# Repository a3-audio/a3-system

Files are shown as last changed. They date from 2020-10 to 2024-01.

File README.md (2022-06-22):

# A³ Audio
Interact live with 3D Audio

## System
- A³ Motion: 4-Channel Motion Sampler
- A³ Mixer: 4-Channel DJ Mixer
- A³ Core: 3D Sound Server

## Homepage
- https://a3-audio.com

## Documentation
- https://doc.a3-audio.com

## Repository
- https://github.com/a3-audio/a3-system

## Contact
- Ticket [github-project](https://github.com/orgs/a3-audio/projects/1)
- Talk [mattermost](https://talk.a3-audio.com/ambisonics)
- E-Mail [contact@a3-audio.com](mailto:contact@a3-audio.com)

## Code of conduct
- Care the docs
- Keep the code clean
- We use [centralized workflow](https://www.git-scm.com/book/en/v2/Distributed-Git-Distributed-Workflows):
  - Don't edit the mainbranch. Use pull requests instead.
  - If you need an own different setup, fork this repo
  - Find us on stage
- Follow the <a href="https://contributor-covenant.org/">Contributor Covenant</a> Code of Conduct

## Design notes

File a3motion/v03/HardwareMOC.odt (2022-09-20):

# Power Supply

# Input

## Poti

### Notes

- The caps are a good idea. You might try putting a small one between the slider and ground.
- Setting REFS0 uses AVCC as the reference. I would set both REFS1 and REFS0 to zero and connect the top of the pot to AREF.
- Two fixed resistors is a good idea to rule out the pot's as the problem.
- Atmel recommends a max of 10K source impedance for 10 bit accuracy. A cap can help with this if the impedance is higher than 10K.10k impedance is what you would get when a 40k pot is in the middle position - 20k to VCC and 20k to GND makes 10k.
- So if you use pots lower than 40k in value, you might not need the caps.

## Encoder

### Schematic

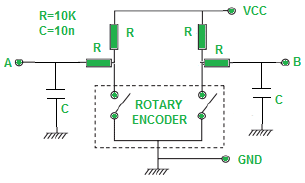
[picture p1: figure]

https://www.electroschematics.com/rotary-encoder-arduino/

with Hardware denoising.

But We will try without and go with software denoising

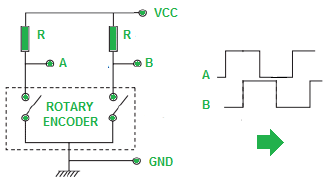
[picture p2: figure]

## Buttons

# LEDs

# TPIC6C595 (LED driver)

## Notes

- https://www.ti.com/lit/ds/symlink/tpic6c595.pdf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

## Overview

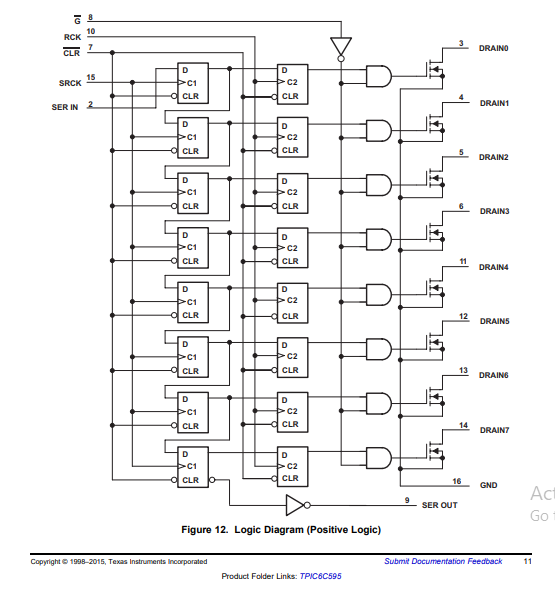
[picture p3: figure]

### Serial-In Interface

This device contains an 8-bit serial-in, parallel-out shift register that feeds an 8-bit D-type storage register. Data transfers through both the shift and storage registers on the rising edge of the shift register clock (SRCK) and the register clock (RCK), respectively. The storage register transfers data to the output buffer when shift register clear (CLR) is high.

### Clear Register

A logical low on (CLR) clears all registers in the device. TI suggests clearing the device during power up or initialization.

### Output Control

Holding the output enable (G) high holds all data in the output buffers low, and all drain outputs are off. Holding (G) low makes data from the storage register transparent to the output buffers. When data in the output buffers is low, the DMOS transistor outputs are off. When data is high, the DMOS transistor outputs have sink-current capability. This pin can also be used for global PWM dimming.

### Cascaded Application

The serial output (SER OUT) allows for cascading of the data from the shift register to additional devices. Connect the device (SEROUT) pin to the next device (SERIN) for daisy Chain.

### Daisy Chain

The typical application of TPIC6C595 is automotive cluster driver. In this example, two TPIC6C595 power shift registers are cascaded and used to turn on LEDs in the cluster panel. In this case, the LED must be updated after all 16 bits of data have been loaded into the serial shift registers. MCU outputs the data to the serial input (SER IN) while clocking the shift register clock (SRCK). After the 16th clock, a pulse to the register clock (RCK) transfers the data to the storage registers. If output enable (G) is low, then the LEDs are turned on corresponding to the status word with ones being on and zeros off. With this simple scheme, MCU can use the SPI interface to turn on 16 LEDs using only two ICs as illustrated in the image

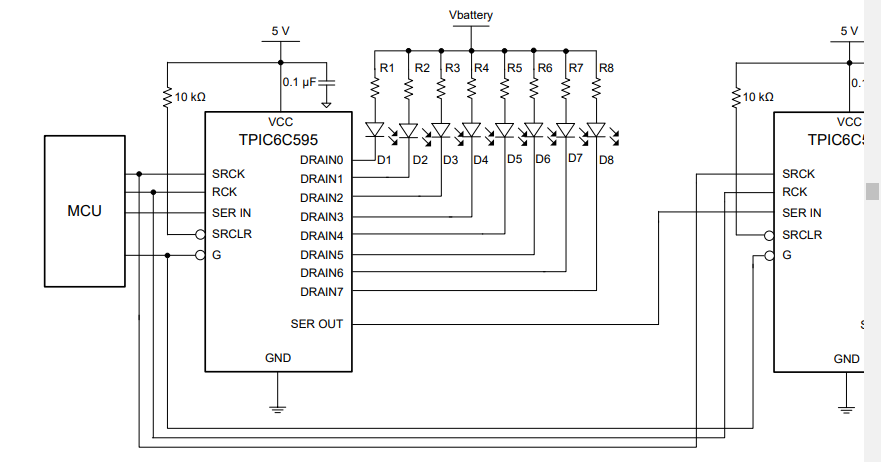
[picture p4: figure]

# Atmega

## ADC

### Notes

- The AVR has a neat feature... you use the internal 2.5V reference for the a/d, and hang a cap on the aref pin to suck up the ripple.
- The reference voltage is just the voltage at the top of the pot. It has a 100n cap to ground.
- I use the ADC Noise Reduction sleep during the conversion. or is this only available on the Atmega169?
- tried the ADC Noise Reduction on the 169, and found it didn't reduce the noise at all,
- siehe seite 196 für noise cancelation https://ww1.microchip.com/downloads/en/DeviceDoc/Atmel-2486-8-bit-AVR-microcontroller-ATmega8_L_datasheet.pdf

### design notes

Aref

- 100nF or 10nF on Aref. Other end on GND.
- Wenn man saubere Spannung hat kann man die auch da als Referenz anlegen

Vcc und Avcc (ADC supply) an 5V.

## I2C

## General IO

# Components

## TPIC6C595

- 1.3$ for DIP
- https://www.mouser.ph/ProductDetail/Texas-Instruments/TPIC6C595N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

## Socket

- 0.37$
- https://www.mouser.ph/ProductDetail/FCI-Amphenol/DILB16P-223TLF?qs=sGAEpiMZZMtneIuP4Zx3qQDrmajaGEu5

## Ceramic Capacitor 100nF

- 0.13$
- https://www.mouser.ph/ProductDetail/Vishay/K104M15X7RF53H5?qs=sGAEpiMZZMskC5GgilGuvlka1JhNGdVz

## Ceramic Capacitor 22pf

- 0.21$
- https://www.mouser.ph/ProductDetail/Vishay/K220J10C0GF5UH5?qs=sGAEpiMZZMvfWfew95%2FxXKwIr%252BteGxkk

## Electrolytic Capacitor 10uF

- 0.083$
- https://www.mouser.ph/ProductDetail/KEMET/ESC106M035AC3AA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

## Tactile Switches

- 2.79$
- https://www.mouser.ph/ProductDetail/CTS/228CMVARGBFR?qs=sGAEpiMZZMv0NwlthflBi6d2CTj%2FILa2s1KfV6ahLRE%3D

## Inductor

- 0.33$
- https://www.mouser.ph/ProductDetail/Bourns/78F100J-TR-RC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

## Header PIN Connector

- Don’t buy at distributor by pack somewhere else
- pitch 2.54mm x and y
- 1 2x2 male
- 1 1x6 female
- 1 1x5 female right angle
- 1 1x5 male right angle
- 2 1x2 female right angle
- 2 1x2 male right angle

## Poti Connector 1x5

# Mini-Lock Wire-to-Board

- Example: https://www.mouser.ph/ProductDetail/Molex/53426-0510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

## Crystal 16mhz

- https://www.mouser.ph/ProductDetail/IQD-Frequency-Products/LFXTAL036391Bulk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

## Encoder 24ppr

- 1.68$

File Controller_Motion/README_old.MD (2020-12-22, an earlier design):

# MOTION CONTROLLER

OSC TRANSMITTER AND PATTERNSAMPLER FOR 3-DIMENSIONAL AUDIO MOTION.

## OVERVIEW:

PLAYMODE
- PLAY
- RUNTIME-EDIT
    - Audio conversion mode (Mono, Stereo, VBAP, Ambisonic)
    - BPM
    - Width
    - Reverb
    - Beat: musical rhythm notation (1/4, 1/8, 3/4...)
    - Bars: length of patternloop
- STOP

SETUPMODE
- SPEAKERSETUP
    - Select Preset
    - Edit Preset
        - Number of loudspeakers
        - Select loudspeaker
        - Adjust position: azimuth, distance, elevation
    - Save and load, ask to enter new name or overwrite
- HEADPHONESETUP
    - Headphone sounds more realistic with fitting hrtf filtercurve
    - Select and load Preset
- PATTERNEDITOR
    - Select bank
    - Edit bank: touch a row or pattern to open "select -> Save -> bank/row/pattern dialog""
    - Save /bank/row/pattern
    - Load selection to buttonmatrix
- OPTIONS
    - Brightness
    - IP-Address, PORT this device
    - IP-Address, PORT to receiver
    - Export settings to usb

## HARDWARE LAYOUT
```
 CH1 CH2 CH3 CH4
  |   |   |   |
  v   v   v   v
|---------------|
| W | W | W | W | <- POTIS FOR WIDTH
|---------------|
| R | R | R | R | <- POTIS FOR REVERB
|---------------|
|               |
|               |
|               |
|               |
| TOUCHDISLPAY  | <- FANCY VISUALISATION OF CHANNELMOVEMENT
|               |
|               |
|               |
|               |
|---------------|
| E | E | E | E | <- ENCODER
|---------------|
| B | B | B | B | <- BUTTONS TO REC AND PLAY MOTION-PATTERNS
|---------------|    |
| B | B | B | B | <--|                        
|---------------|    |                 THE
| B | B | B | B | <--|            BUTTON-MATRIX 
|---------------|    |
| B | B | B | B | <--|
|---------------|
```

## DISPLAY LAYOUT
The touchscreen displays a lot of information but it makes sense in order 
to control and see all information on one fingertip.

```
       ch1            ch2           ch3            ch4        <- INFOFIELDS        
        |              |             |              |                 
        v              v             v              v                 
|-----------------------------------------------------------|         
| MODE:   MONO | MODE:   STER | MODE:   VBAP | MODE:   AMBI |         
| BEAT:   1/4  | BEAT:   1/4  | BEAT:   1/4  | BEAT:   1/4  |
| BARS:   4    | BARS:   4    | BARS:   4    | BARS:   4    |    
| WIDTH:  -    | WIDTH:  30°  | WIDTH:  20°  | WIDTH:  30°  |         
| REVERB: -    | REVERB: 30%  | REVERB: 30%  | REVERB: 30%  | 
| BPM:    128  | BPM:    128  | BPM:    128  | BPM:    128  |
|-----------------------------------------------------------|
|                            ch1                            |          
|                            sp2                            |
|                      __----ch2----__                      |
|                     L               R                     |
|                                                           |
|                                                           |
|                                                           |
|                                                           |
|  sp1                                                 sp3  |
|  ch1                                                 ch1  |
|                                                           |
|        R                                            L     |
|         |                                           |     | <- EAGLEVIEW: CURRENT SOUNDFIELD
|          |                                         |      |    
|         ch3                                       |       |    
|          |                                       ch4      |    
|           |                                       |       |
|            L                                     |        |
|                                                 |         |
|                                                 R         |
|                                                           |
|                                                           |
|                                                           |
|                                                           |
|             sp5                         sp4               |
|             ch1                         ch1               |
|                                                           |    
||1-------2-------3-------4-------5-------6-------7-------| | <- RUNTIME-EDIT: PATTERNLENGTH   
||->->->->->->->->->                                      | | <- RUNTIME-EDIT: PATTERNPROGRESS
|-----------------------------------------------------------|    
| RCV:192.168.178.125:1234|SND:192.168.178.126:1232|BPM:128 | <- SYSTEMVIEW
|-----------------------------------------------------------|

TOUCHDISPLAY LEGEND:
- INFOFIELD: COLORS - 4 channels, 4 infofield areas, 4 different colors
- INFOFIELD: MODE - The Stereosource will be converted to Mono, Stereo, VBAP or Ambisonic
- INFOFIELD: WIDTH - How wide your sources spread in the sphere (exept monomode)
- INFOFIELD: REVERB - An Ambisonic Reverb reflects from all directions (except monomode)
- INFOFIELD: BPM - Calculated BPM for each Track, cool to run musicious motionpatterns
- INFOFIELD: BEAT - Map motionpatterns on estimated BPM
- INFOFIELD: BARS - Lenght of motionsequenz

- EAGLEVIEW: SP - The speakerposition
- EAGLEVIEW: CH - The channelposition (channels are colorcoded)
- EAGLEVIEW: LR - The width of a stereosource
- EAGLEVIEW: .. - These thin colored lines connecting straight to corresponding infofield

- SYSTEMVIEW: RCV - This device OSC input
- SYSTEMVIEW: SND - This device OSC output
- SYSTEMVIEW: BPM - Master BPM
```
## PLAYMODE
- Encoder 1-4: Push

### PLAYMODE: PLAY
- Encoder 1-4 Push: Toggle RUNTIME-EDIT Mode for this channel
- Encoder 1-4 Double Push: Enter Setup Page 1-4
- Buttonmatrix Push: play pattern
- Buttonmatrix Double Push: toggle repeat 

### PLAYMODE: RUNTIME-EDIT
- Encoder - Push: Toggle through INFOFIELD-options
- Encoder - Turn: Adjust option
    - MODE: mono, stereo, vbap, ambisonic
    - BEAT: 1/4, 1/8, 1/16, 2/3, ... 
    - BARS: length of patternloop
    - WIDTH: Spread stereo
    - REVERB: Adjust reverblevel
- Touchdisplay onTouch: Records Motion to cachefile
- Touchdisplay onRelease: Plays Motion from cachefile
- Buttonmatrix long press: Stores cachefile to BUTTON
- Encorder Double Push: Exit to PLAYMODE

### PLAYMODE: STOP
- Somewhere should be a resetbutton, or steady scenes in patterns?

## SETUPMODE
Encoder 1-4: Double-Push. 

### SPEAKERSETUP: SELECT PRESET
Encoder 1: Double-Push
- Encoder 1 Turn: Select Preset - SELECT overlay
- Encoder 1 Push: Load Preset 

### SPEAKERSETUP: EDIT PRESET
Encoder 2: Double-Push
- Encoder 1 Turn: Set Number of outputs
- Encoder 2 Turn: Select output
- Encoder 3 Turn: Set Azimuth for selected output
- Encoder 4 Turn: Set Distance for selected output

### SPEAKERSETUP: SAVE AND LOAD
- Display Button SAVE: SAVE TO .. overlay
- Display Button DISCARD: Discard changes
- Display Button ENABLE: Upload Speakerlayout to Audioengine
- Display Button EXIT: Return to PLAYMODE and open dialog "save changes?" [yes, dismiss]
```
|-----------------------------------------------|
| SPEAKERSETUP                                  | <- SPEAKERSETUP: SELECT PRESET
| 5 CHANNEL CIRCLE WITH DISTANCE 4.5m           |
|-----------------------------------------------|
| OUTPUTS  |  SELECT   |  AZIMUTH  |  DISTANCE  | <- SPEAKERSETUP: EDIT PRESET
| 5        |  sp1      |  -80°     |  4.5m      |
|-----------------------------------------------|
|                                               |
|                     sp2                       |
|        |sp1|                    sp3           |
|                                               |
|                                               | <- VISUALISATION OF SPEAKERSETUP
|                                               |
|                                               |  
|               sp5        sp4                  |
|                                               |
|                                               |
|-----------------------------------------------|
|-----------------------------------------------|
|          |           |            |           |
|   SAVE   |  DISCARD  |   ENABLE   |   EXIT    | <- SPEAKERSETUP: SAVE AND LOAD                   
|          |           |            |           |
------------------------------------------------|

SELECT and SAVE TO.. - OVERLAY
- Encoder 1 Turn: select
- Encoder 1 push: enter selection

|-----------------------------------------------|
| SPEAKERSETUP                                  |
| 5 CHANNEL CIRCLE WITH DISTANCE 4.5m           |
|-----------------------------------------------|
| OUTPUTS  |  SELECT   |  AZIMUTH  |  DISTANCE  |             
| 5        |  sp1      |  -80°     |  4.5m      |
|-----------------------------------------------|
|                                               |
|                     sp2                       |
|    |-------------------------------------|    |
|    |             Burning Man 2021        |    |
|    | selected -> GARBICZ 2019            |    |                        
|    |             Gardelegen 2018         |    |
|    |--------------------------------------    |  
|               sp5        sp4                  |
|                                               |
|                                               |
|-----------------------------------------------|
|-----------------------------------------------|
|          |           |            |           |
|   SAVE   |  DISCARD  |   ENABLE   |   EXIT    |                                                 
|          |           |            |           |
|-----------------------------------------------|

A common workflow, starting from PLAYMODE:
- Encoder 1: Double Push - enter SPEAKERSETUP
- Encoder 1: Turn - Select speakerlayout
- Encoder 1: Push - Edit speakerlayout
- Encoder 2: Double Push - enter SETUPMODE LEVEL 2
- Encoder 1: Turn - Adjust number of speaker outputs
- Encoder 2: Turn - Select speaker 1
- Encoder 3: Turn - Adjust Azimuth of speaker 1(-180°, 180°)
- Encoder 4: Turn - Adjust Distanz of speaker 2
- Repeat the last 3 steps for all your speaker
- Display Button SAVE: Save your speakerlayout
- Display Button ENABLE: Upload your setup to audioengine
- Display Button EXIT: Exit to PLAYMODE
```

### HEADPHONESETUP
Encoder 3: Double-Push
- Encoder 1 Turn: Select preset - SELECT overlay
- Encoder 1 Push: Enable preset

### PATTERNEDITOR: LAYOUT SELECT / EDIT
Encoder 4: Double-Push
- Encoder 1 Turn: Select BANK preset - SELECT overlay
- Encoder 1 Push: Load BANK preset to editor
- Encoder 2 Turn: Select ROW preset - SELECT Overlay
    - Encoder 1-4 Push: Load ROW to BANK
    - Encoder 1-4 Hold: Load ROW on BUTTONMATRIX
- Display Button PATTERN: Select PATTERN preset - SELECT overlay
    - Encoder 1 Turn: Select PATTERN preset
    - Encoder 1 Push: Load PATTERN preset to PATTERN

### PATTERNEDITOR: SAVE AND LOAD
- Display Button SAVE: SAVE TO .. overlay
- Display Button DISCARD: Discard changes
- Display Button ENABLE: Upload patternlayout to audioengine
- Display Button EXIT: Return to PLAYMODE and open dialog "save changes?" [yes, dismiss]

```
|-----------------------------------------------|
| PRESET BANK/ROW/PATTERN                       | <- LEVEL 3
| Presetbank: user                              |
|-----------------------------------------------|
|   ROW 1   |   ROW 2   |   ROW 3   |   ROW 4   | <- 
|-----------------------------------------------|
|           |           |           |           |
|  PATTERN  |  PATTERN  |  PATTERN  |  PATTERN  |
|           |           |           |           |
|-----------------------------------------------|
|           |           |           |           |
| 1/4 right |  PATTERN  |  PATTERN  |  PATTERN  |
|           |           |           |           |
|-----------------------------------------------| <- PREVIEW BUTTONMATRIXLAYOUT
|           |           |           |           | 
| 1/8 rand  |  PATTERN  |  PATTERN  |  PATTERN  |
|           |           |           |           |
|-----------------------------------------------|
|           |           |           |           |
| 1/16 diag |  PATTERN  |  PATTERN  |  PATTERN  |
|           |           |           |           |
|-----------------------------------------------|
|-----------------------------------------------|
|           |           |           |           |
|   SAVE    |  DISCARD  |  ENABLE   |   EXIT    |                                  
|           |           |           |           |
------------------------------------------------|

SELECT and SAVE TO.. - OVERLAY
- Encoder 1 Turn: Select Buttonpattern
- Encoder 1 Push: Load Buttonpattern

|-------------------------------------------------|
| BUTTONMATRIX LAYOUT                             |  <- LEVEL 3
| USERSPACE 1                                     |
|-------------------------------------------------|
|   ROW 1   |   ROW 2    |   ROW 3    |   ROW 4   |
|-------------------------------------------------|
|           |            |            |           |
| 1/4 left  |    ...     |    ...     |    ...    |
|           |            |            |           |
|-------------------------------------------------|
|           |            |            |           |
| 1/4 |-------------------------------------|.    |
|     |             1/4 left                |     |
|-----| selected -> 1/4 RIGHT               |-----| <- PAD-SELECTION OVERLAY
|     |             1/8 random              |     |                           
| 1/8 |--------------------------------------.    |
|           |            |            |           |
|-------------------------------------------------|
|           |            |            |           |
| 1/16 left |    ...     |    ...     |    ...    |
|           |            |            |           |
|-------------------------------------------------|
|-------------------------------------------------|
|                        |                        |
|      SAVE & EXIT       |     DISCARD & EXIT     |                                  
|                        |                        |
--------------------------------------------------|

PATTERNEDITOR BACKEND:
Example - Presetbank "smooth" 

Stored informations:
- Bankname
- Banklayout
- Rownames
- Rowlayouts
- Patternnames
- Patternconfig

If folder smooth contains a .ini file and subfolders, its a bank.
If it contains .ini file and .ptn files, its a row.

└── glitter
└── smooth
    ├── smooth.ini
    ├── Antropofagia
    │   ├── layout.ini
    │   ├── drop.ptn
    │   ├── intro.ptn
    │   ├── steady.ptn
    │   └── woof.ptn
    ├── Kaluma
    │   ├── layout.ini
    │   ├── drop.ptn
    │   ├── intro.ptn
    │   ├── steady.ptn
    │   └── woof.ptn
    ├── LostMemory
    │   ├── layout.ini
    │   ├── drop.ptn
    │   ├── intro.ptn
    │   ├── steady.ptn
    │   └── woof.ptn
    └── SixthSense
        ├── layout.ini
        ├── drop.ptn
        ├── intro.ptn
        ├── steady.ptn
        └── woof.ptn

A common Workflow starting from PLAYMODE:
- Encoder 3 Double push: Enter PATTERNEDITOR
- Encoder 1 Turn: Select presetbank
- Encoder 1 Push: Edit selected presetbank 
- Encoder 2 Turn: Select strip
- Display Button ROW 1-4: Load selected strip
- Encoder 3 Turn: Select pattern
- Display Button PATTERN: Load selected PATTERN
- Display Button SAVE: SAVE TO .. popup
- Display Button DISCARD: Discard changes
- Display Button ENABLE: Load current Layout to Buttonmatrix
- Display Button EXIT: Return to PLAYMODE and open dialog "save changes?" [yes, dismiss]

Note: Factorypresets are writeprotected but you can edit and store them as userpreset.
You can store motions in pattern, pattern in rows and rows in banks banks.
```

### OPTIONS
- Brightness
- IP-Address and Port Motioncontroller
- IP-Address and Port audioengine
- Export settings to usb

## OSC
``` 
# TRANSMIT
/ambijockey/moc/ch/1-4/mode/ [0-3] (Mono, Stereo, VBAP, Ambisonic)
/ambijockey/moc/ch/1-4/motion/ xy [0-1]
/ambijockey/moc/ch/1-4/width/ [0-1]
/ambijockey/moc/ch/1-4/reverb/ [0-1]

/ambijockey/moc/speakersetup/n [1-24]
/ambijockey/moc/speakersetup/n/azimuth [-180-180]
/ambijockey/moc/speakersetup/n/Distance [m]

# RECEIVE
/ambijockey/moc/ch/1-4/motion/ xy [0-1]
/ambijockey/moc/ch/1-4/vu/ [0-1]
/ambijockey/moc/ch/1-4/bpm/ [80-180]
/ambijockey/moc/master/bpm/ [80-180]
```

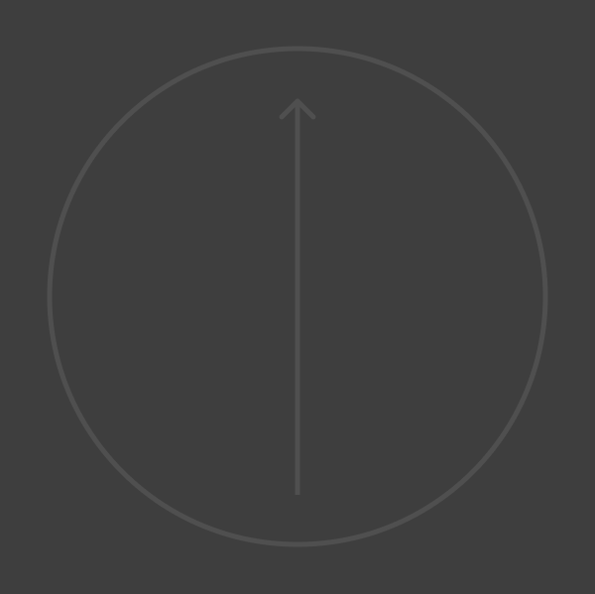
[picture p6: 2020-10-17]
Controller_Motion/software/python/GUI/Pix/MoverMeterBG.png

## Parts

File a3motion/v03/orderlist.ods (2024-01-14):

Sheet: Sheet1
Wie viele tatsächlich benätigt werden |  |  | Bauteil Beschreibung
rpi connect | poti | main | name | bauform | suchbegriff | wie viel ordern | Variation | link für order
 |  | 5 | 100nF | 1206 | Cap | 1 | 100nF | AE:32966490820
 |  | 1 | 10uF | D 4.0mm P1.5 | Elko | 1 | 25V10uF 5x11mm 50p | AE: 1005001429282858
 |  | 1 | 1x5 | P2.54 | Horiz Pinconnector male | 2 | 1row curved male | https://www.aliexpress.com/item/4001112688385.html?spm=a2g0o.cart.0.0.6f5f38dak9MJmX&mp=1
 |  | 1 | 1x5 | P2.54 | Horiz Pinconnector female | 2 | 1row curved female | https://www.aliexpress.com/item/4001112688385.html?spm=a2g0o.cart.0.0.6f5f38dak9MJmX&mp=1
 | 1 | 1 | 1x5 | P2.50 | JST_XH_B5B-XH-A P2.50mm | 2 |  | https://www.digikey.de/de/products/detail/jst-sales-america-inc/B5B-XH-A-LF-SN/1530483
 |  | 1 | 1x3 | P2.54 | Vert Pinconnector male | 0 |  | ok Empty
 |  | 1 | 2x2 | P2.54 | Vert Pinconnector male | 1 | 2row male | https://www.aliexpress.com/item/4001112688385.html?spm=a2g0o.cart.0.0.6f5f38dak9MJmX&mp=1
 |  | 3 | 0R | 1206 | Resistor | 1 | 0R | https://www.aliexpress.com/item/1005001794416354.html?spm=a2g0o.cart.0.0.6f5f38dak9MJmX&mp=1
 | 2 | 6 | 4k7 | 1206 | Resistor | 1 | 4.7k | https://www.aliexpress.com/item/1005001794416354.html?spm=a2g0o.cart.0.0.6f5f38dak9MJmX&mp=1
 |  | 8 | 155R | 1206 | Resistor | 1 | 155R | https://www.aliexpress.com/item/1005001794416354.html?spm=a2g0o.cart.0.0.6f5f38dak9MJmX&mp=1
 |  | 4 | 100R | 1206 | Resistor | 1 | 100R | https://www.aliexpress.com/item/1005001794416354.html?spm=a2g0o.cart.0.0.6f5f38dak9MJmX&mp=1
 |  | 2 | 27k | 1206 | Resistor | 1 | 27k | https://www.aliexpress.com/item/1005001794416354.html?spm=a2g0o.cart.0.0.6f5f38dak9MJmX&mp=1
 |  | 4 | Buttons |  | MO:228CMVARGBFR | 4 |  | https://www.mouser.de/ProductDetail/CTS-Electronic-Components/228CMVARGBFR?qs=gTYE2QTfZfSFpUQ%252Bb6QA4w%3D%3D
 |  | 1 | Rotary_Encoder_Switch |  | PEC11R-4230K-S0024 | 1 |  | https://www.digikey.de/de/products/detail/bourns-inc/PEC11R-4230K-S0024/7314923
 |  | 2 | SOIC-16_3.9x9.9mm | P1.27mm | TPIC6C595 | 2 |  | https://www.mouser.de/ProductDetail/STMicroelectronics/STPIC6C595MTR?qs=w3gjcs3NwcgP4BoIb%252B0GuQ%3D%3D
 |  | 1 | ATtiny1626 |  | MO:556-ATTINY1626-SF | 1 |  | https://www.mouser.de/ProductDetail/Microchip-Technology-Atmel/ATTINY1626-SF?qs=vmHwEFxEFR87MXV%2FJYMLYg%3D%3D
 | 2 |  | 50k Poti |  | DK:PT01-D130D-B503 | 1 | 50K | https://www.aliexpress.com/item/4001230670074.html?spm=a2g0o.cart.0.0.6f5f38dak9MJmX&mp=1
1 |  |  | 1x5 | P2.54 | Vert Pinconnector male | 4 |  | https://www.aliexpress.com/item/4001112688385.html?spm=a2g0o.cart.0.0.6f5f38dak9MJmX&mp=1
1 |  |  | 2x5 | P2.54 | Vert Pinconnector female | 2 | 2row female | https://www.aliexpress.com/item/4001112688385.html?spm=a2g0o.cart.0.0.6f5f38dak9MJmX&mp=1
2 |  |  | BSS138 | SOT-23 | DK:BSS138LT1G | 2 |  | https://www.aliexpress.com/item/1948601004.html?spm=a2g0o.cart.0.0.6f5f38dak9MJmX&mp=1
4 |  |  | 10k | 1206 | Resistor | 1 | 10k | https://www.aliexpress.com/item/1005001794416354.html?spm=a2g0o.cart.0.0.6f5f38dak9MJmX&mp=1
1 |  |  | USB-C |  | MO:640-USB4125-GF-A-190 | 1 |  | https://www.mouser.de/ProductDetail/GCT/USB4125-GF-A-0190?qs=QNEnbhJQKvbCz4hEJBS24w%3D%3D
 |  |  |  |  |  |  |  | https://www.aliexpress.com/item/1005001429282858.html?spm=a2g0o.cart.0.0.76f038dagCkkKq&mp=1

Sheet: order
Wie viele tatsächlich benätigt werden |  |  | Bauteil Beschreibung
rpi connect | poti | main | name | bauform | suchbegriff | wie viel ordern | Variation | link für order
 | 1 | 1 | 1x5 | P2.50 | JST_XH_B5B-XH-A P2.50mm | 2 |  | https://www.digikey.de/de/products/detail/jst-sales-america-inc/B5B-XH-A-LF-SN/1530483
 |  | 1 | Rotary_Encoder_Switch |  | PEC11R-4230K-S0024 | 1 |  | https://www.digikey.de/de/products/detail/bourns-inc/PEC11R-4230K-S0024/7314923
 |  | 2 | SOIC-16_3.9x9.9mm | P1.27mm | TPIC6C595 | 2 |  | https://www.digikey.de/de/products/detail/stmicroelectronics/STPIC6C595MTR/634787
 |  | 3 | 0R | 1206 | Resistor | 1 | 0R | https://www.aliexpress.com/item/1005001794416354.html?spm=a2g0o.cart.0.0.6f5f38dak9MJmX&mp=1
 | 2 | 6 | 4k7 | 1206 | Resistor | 1 | 4.7k | https://www.aliexpress.com/item/1005001794416354.html?spm=a2g0o.cart.0.0.6f5f38dak9MJmX&mp=1
 |  | 8 | 155R | 1206 | Resistor | 1 | 155R | https://www.aliexpress.com/item/1005001794416354.html?spm=a2g0o.cart.0.0.6f5f38dak9MJmX&mp=1
 |  | 4 | 100R | 1206 | Resistor | 1 | 100R | https://www.aliexpress.com/item/1005001794416354.html?spm=a2g0o.cart.0.0.6f5f38dak9MJmX&mp=1
 |  | 2 | 27k | 1206 | Resistor | 1 | 27k | https://www.aliexpress.com/item/1005001794416354.html?spm=a2g0o.cart.0.0.6f5f38dak9MJmX&mp=1
4 |  |  | 10k | 1206 | Resistor | 1 | 10k | https://www.aliexpress.com/item/1005001794416354.html?spm=a2g0o.cart.0.0.6f5f38dak9MJmX&mp=1
 | 2 |  | 50k Poti |  | DK:PT01-D130D-B503 | 1 | 50K | https://www.aliexpress.com/item/4001230670074.html?spm=a2g0o.cart.0.0.6f5f38dak9MJmX&mp=1
2 |  |  | BSS138 | SOT-23 | DK:BSS138LT1G | 2 |  | https://www.aliexpress.com/item/1948601004.html?spm=a2g0o.cart.0.0.6f5f38dak9MJmX&mp=1
 |  | 1 | 10uF | D 4.0mm P1.5 | Elko | 1 | 25V10uF 5x11mm 50p | https://www.aliexpress.com/item/1005001429282858.html?spm=a2g0o.cart.0.0.76f038dagCkkKq&mp=1
 |  | 5 | 100nF | 1206 | Cap | 1 | 100nF | https://www.aliexpress.com/item/32966490820.html?spm=a2g0o.cart.0.0.693a38da32krFN&mp=1
 |  | 1 | 1x5 | P2.54 | Horiz Pinconnector male | 2 | 1row curved male | https://www.aliexpress.com/item/4001112688385.html?spm=a2g0o.cart.0.0.6f5f38dak9MJmX&mp=1
 |  | 1 | 1x5 | P2.54 | Horiz Pinconnector female | 2 | 1row curved female | https://www.aliexpress.com/item/4001112688385.html?spm=a2g0o.cart.0.0.6f5f38dak9MJmX&mp=1
 |  | 1 | 2x2 | P2.54 | Vert Pinconnector male | 1 | 2row male | https://www.aliexpress.com/item/4001112688385.html?spm=a2g0o.cart.0.0.6f5f38dak9MJmX&mp=1
1 |  |  | 1x5 | P2.54 | Vert Pinconnector male | 4 |  | https://www.aliexpress.com/item/4001112688385.html?spm=a2g0o.cart.0.0.6f5f38dak9MJmX&mp=1
1 |  |  | 2x5 | P2.54 | Vert Pinconnector female | 2 | 2row female | https://www.aliexpress.com/item/4001112688385.html?spm=a2g0o.cart.0.0.6f5f38dak9MJmX&mp=1
1 |  |  | USB-C |  | MO:640-USB4125-GF-A-190 | 1 |  | https://www.mouser.de/ProductDetail/GCT/USB4125-GF-A-0190?qs=QNEnbhJQKvbCz4hEJBS24w%3D%3D
 |  | 1 | ATtiny1626 |  | MO:556-ATTINY1626-SF | 1 |  | https://www.mouser.de/ProductDetail/Microchip-Technology-Atmel/ATTINY1626-SF?qs=vmHwEFxEFR87MXV%2FJYMLYg%3D%3D
 |  | 4 | Buttons |  | MO:228CMVARGBFR | 4 |  | https://www.mouser.de/ProductDetail/CTS-Electronic-Components/228CMVARGBFR?qs=gTYE2QTfZfSFpUQ%252Bb6QA4w%3D%3D
 |  | 1 | 1x3 | P2.54 | Vert Pinconnector male | 0 |  | ok Empty

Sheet: calc
poti pcb (6x) | 21.06
Button pcb (6x) | 61.62
rpi connector (3x) | 10.98
AliExpress | 71.27
DigiKey | 39.16
mouser | 95.22
 | 299.31

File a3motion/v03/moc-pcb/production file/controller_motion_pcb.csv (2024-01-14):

Source: | C:\Users\tirii\Documents\Ambisonic\a3-hardware\a3motion\v03\Mainboard-pcb\controller_motion_pcb.kicad_sch
Date: | 27/09/2022 13:00:52
Tool: | Eeschema (6.0.0)
Generator: | C:\Program Files\KiCad\6.0\bin\scripting\plugins/bom_csv_grouped_by_value.py
Component Count: | 42
Individual Components:
Item | Qty | Reference(s) | Value | LibPart | Footprint | Datasheet | Description | Height | Manufacturer_Name | Manufacturer_Part_Number | Mouser Part Number | Mouser Price/Stock
 |  | C1 | 100nF | Device:C | Capacitor_SMD:C_1206_3216Metric_Pad1.33x1.80mm_HandSolder | DK:1206B104K500BD
 |  | C2 | 100nF | Device:C | Capacitor_SMD:C_1206_3216Metric_Pad1.33x1.80mm_HandSolder | DK:1206B104K500BD
 |  | C3 | 100nF | Device:C | Capacitor_SMD:C_1206_3216Metric_Pad1.33x1.80mm_HandSolder | DK:1206B104K500BD
 |  | C4 | 100nF | Device:C | Capacitor_SMD:C_1206_3216Metric_Pad1.33x1.80mm_HandSolder | DK:1206B104K500BD
 |  | C5 | 10uF | Device:CP | Capacitor_THT:CP_Radial_D4.0mm_P1.50mm | DK:35ML10MEFCT54X7
 |  | C6 | 100nF | Device:C | Capacitor_SMD:C_1206_3216Metric_Pad1.33x1.80mm_HandSolder | DK:1206B104K500BD
 |  | J1 | SPI_Female | Connector:Conn_01x05_Female | Connector_PinSocket_2.54mm:PinSocket_1x05_P2.54mm_Horizontal | DK:PPTC051LGBN-RC
 |  | J2 | SPI_Male | Connector:Conn_01x05_Male | Connector_PinHeader_2.54mm:PinHeader_1x05_P2.54mm_Horizontal | DK:61300511021
 |  | J3 | Conn_01x05 | Connector:Conn_01x05_Female | 3dAudioFoot:JST_XH_B5B-XH-A_1x05_P2.50mm_Vertical | DK:B5B-XH-A
 |  | J4 | UPDI_Interface | Connector:Conn_01x03_Male | Connector_PinHeader_2.54mm:PinHeader_1x03_P2.54mm_Vertical | DK:61300311121
 |  | J5 | Programm_Jumper | Connector:Conn_02x02_Male | Connector_PinHeader_2.54mm:PinHeader_2x02_P2.54mm_Vertical | DK:61300421121
 |  | R1 | 0R | Device:R | Resistor_SMD:R_1206_3216Metric_Pad1.30x1.75mm_HandSolder | 1206 Resistor 5%
 |  | R2 | 0R | Device:R | Resistor_SMD:R_1206_3216Metric_Pad1.30x1.75mm_HandSolder | 1206 Resistor 5%
 |  | R3 | 4k7 | Device:R | Resistor_SMD:R_1206_3216Metric_Pad1.30x1.75mm_HandSolder | 1206 Resistor 5%
 |  | R4 | 4k7 | Device:R | Resistor_SMD:R_1206_3216Metric_Pad1.30x1.75mm_HandSolder | 1206 Resistor 5%
 |  | R5 | 165 | Device:R | Resistor_SMD:R_1206_3216Metric_Pad1.30x1.75mm_HandSolder | 1206 Resistor 5%
 |  | R6 | 155 | Device:R | Resistor_SMD:R_1206_3216Metric_Pad1.30x1.75mm_HandSolder | 1206 Resistor 5%
 |  | R7 | 100 | Device:R | Resistor_SMD:R_1206_3216Metric_Pad1.30x1.75mm_HandSolder | 1206 Resistor 5%
 |  | R8 | 165 | Device:R | Resistor_SMD:R_1206_3216Metric_Pad1.30x1.75mm_HandSolder | 1206 Resistor 5%
 |  | R9 | 155 | Device:R | Resistor_SMD:R_1206_3216Metric_Pad1.30x1.75mm_HandSolder | 1206 Resistor 5%
 |  | R10 | 100 | Device:R | Resistor_SMD:R_1206_3216Metric_Pad1.30x1.75mm_HandSolder | 1206 Resistor 5%
 |  | R11 | 165 | Device:R | Resistor_SMD:R_1206_3216Metric_Pad1.30x1.75mm_HandSolder | 1206 Resistor 5%
 |  | R12 | 155 | Device:R | Resistor_SMD:R_1206_3216Metric_Pad1.30x1.75mm_HandSolder | 1206 Resistor 5%
 |  | R13 | 100 | Device:R | Resistor_SMD:R_1206_3216Metric_Pad1.30x1.75mm_HandSolder | 1206 Resistor 5%
 |  | R14 | 165 | Device:R | Resistor_SMD:R_1206_3216Metric_Pad1.30x1.75mm_HandSolder | 1206 Resistor 5%
 |  | R15 | 155 | Device:R | Resistor_SMD:R_1206_3216Metric_Pad1.30x1.75mm_HandSolder | 1206 Resistor 5%
 |  | R16 | 100 | Device:R | Resistor_SMD:R_1206_3216Metric_Pad1.30x1.75mm_HandSolder | 1206 Resistor 5%
 |  | R17 | 27k | Device:R | Resistor_SMD:R_1206_3216Metric_Pad1.30x1.75mm_HandSolder | 1206 Resistor 5%
 |  | R18 | 27k | Device:R | Resistor_SMD:R_1206_3216Metric_Pad1.30x1.75mm_HandSolder | 1206 Resistor 5%
 |  | R19 | 4k7 | Device:R | Resistor_SMD:R_1206_3216Metric_Pad1.30x1.75mm_HandSolder | 1206 Resistor 5%
 |  | R20 | 4K7 | Device:R | Resistor_SMD:R_1206_3216Metric_Pad1.30x1.75mm_HandSolder | 1206 Resistor 5%
 |  | R21 | 4K7 | Device:R | Resistor_SMD:R_1206_3216Metric_Pad1.30x1.75mm_HandSolder | 1206 Resistor 5%
 |  | R22 | 4k7 | Device:R | Resistor_SMD:R_1206_3216Metric_Pad1.30x1.75mm_HandSolder | 1206 Resistor 5%
 |  | R23 | 0R | Device:R | Resistor_SMD:R_1206_3216Metric_Pad1.30x1.75mm_HandSolder | 1206 Resistor 5%
 |  | S1 | 228CMVARGBFR | 3dAudioSym:228CMVARGBFR | 3dAudioFoot:228CMVARGBFR_SMD | MO:228CMVARGBFR | Tactile Switches Color Red,Green,Blue SMD Gullwing | 7.3 | CTS | 228CMVARGBFR | 774-228CMVARGBFR | https://www.mouser.co.uk/ProductDetail/CTS-Electronic-Components/228CMVARGBFR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
 |  | S2 | 228CMVARGBFR | 3dAudioSym:228CMVARGBFR | 3dAudioFoot:228CMVARGBFR_SMD | MO:228CMVARGBFR | Tactile Switches Color Red,Green,Blue SMD Gullwing | 7.3 | CTS | 228CMVARGBFR | 774-228CMVARGBFR | https://www.mouser.co.uk/ProductDetail/CTS-Electronic-Components/228CMVARGBFR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
 |  | S3 | 228CMVARGBFR | 3dAudioSym:228CMVARGBFR | 3dAudioFoot:228CMVARGBFR_SMD | MO:228CMVARGBFR | Tactile Switches Color Red,Green,Blue SMD Gullwing | 7.3 | CTS | 228CMVARGBFR | 774-228CMVARGBFR | https://www.mouser.co.uk/ProductDetail/CTS-Electronic-Components/228CMVARGBFR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
 |  | S4 | 228CMVARGBFR | 3dAudioSym:228CMVARGBFR | 3dAudioFoot:228CMVARGBFR_SMD | MO:228CMVARGBFR | Tactile Switches Color Red,Green,Blue SMD Gullwing | 7.3 | CTS | 228CMVARGBFR | 774-228CMVARGBFR | https://www.mouser.co.uk/ProductDetail/CTS-Electronic-Components/228CMVARGBFR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
 |  | SW1 | Rotary_Encoder_Switch | Device:Rotary_Encoder_Switch | 3dAudioFoot:PEC11R4230KS0024 | DK:PEC11R-4230K-S0024
 |  | U1 | TPIC6C595 | 3dAudioSym:TPIC6C595 | Package_SO:SOIC-16_3.9x9.9mm_P1.27mm | MO:511-STPIC6C595MTR
 |  | U2 | TPIC6C595 | 3dAudioSym:TPIC6C595 | Package_SO:SOIC-16_3.9x9.9mm_P1.27mm | MO:511-STPIC6C595MTR
 |  | U3 | ATtiny1626 | 3dAudioSym:ATtiny1626 | 3dAudioFoot:attiny1626 | MO:556-ATTINY1626-SF
 | DK ? digikey MO ? Mouser

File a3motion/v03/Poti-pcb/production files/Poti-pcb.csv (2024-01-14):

Source: | C:\Users\tirii\Documents\Ambisonic\a3-hardware\a3motion\v03\Poti-pcb\Poti-pcb.kicad_sch
Date: | 27/09/2022 13:05:09
Tool: | Eeschema (6.0.0)
Generator: | C:\Program Files\KiCad\6.0\bin\scripting\plugins/bom_csv_grouped_by_value.py
Component Count: | 5
Individual Components:
Item | Qty | Reference(s) | Value | LibPart | Footprint | Datasheet
 |  | J1 | Conn_01x05_Male | Connector:Conn_01x05_Male | 3dAudioFoot:JST_XH_B5B-XH-A_1x05_P2.50mm_Vertical | DK:B5B-XH-A
 |  | R1 | 4k7 | Device:R | Resistor_SMD:R_1206_3216Metric_Pad1.30x1.75mm_HandSolder | 1206 5%
 |  | R2 | 4k7 | Device:R | Resistor_SMD:R_1206_3216Metric_Pad1.30x1.75mm_HandSolder | 1206 5%
 |  | RV1 | 10k Poti | Device:R_Potentiometer | Potentiometer_THT:Potentiometer_Alpha_RD901F-40-00D_Single_Vertical_CircularHoles | DK:PT01-D130D-B503
 |  | RV2 | 10k Poti | Device:R_Potentiometer | Potentiometer_THT:Potentiometer_Alpha_RD901F-40-00D_Single_Vertical_CircularHoles | DK:PT01-D130D-B503
 | DK ? Digikey MO ? Mouser

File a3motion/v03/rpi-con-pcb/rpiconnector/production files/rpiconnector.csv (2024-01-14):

Source: | C:\Users\tirii\Documents\Ambisonic\a3-hardware\a3motion\v03\RPIconnector\rpiconnector\rpiconnector.kicad_sch
Date: | 27/09/2022 12:04:25
Tool: | Eeschema (6.0.0)
Generator: | C:\Program Files\KiCad\6.0\bin\scripting\plugins/bom_csv_grouped_by_value.py
Component Count: | 9
Individual Components:
Item | Qty | Reference(s) | Value | LibPart | Footprint | Datasheet
 |  | J1 | Conn_01x05_Male | Connector:Conn_01x05_Male | Connector_PinHeader_2.54mm:PinHeader_1x05_P2.54mm_Vertical | DK:61300511121
 |  | J2 | Conn_02x05_Odd_Even | Connector_Generic:Conn_02x05_Odd_Even | Connector_PinHeader_2.54mm:PinHeader_2x05_P2.54mm_Vertical | MO:649-68046-605PLF
 |  | Q1 | BSS138 | Transistor_FET:BSS138 | Package_TO_SOT_SMD:SOT-23 | DK:BSS138LT1G
 |  | Q2 | BSS138 | Transistor_FET:BSS138 | Package_TO_SOT_SMD:SOT-23 | DK:BSS138LT1G
 |  | R1 | 10k | Device:R | Resistor_SMD:R_1206_3216Metric_Pad1.30x1.75mm_HandSolder | 1206 5%
 |  | R2 | 10k | Device:R | Resistor_SMD:R_1206_3216Metric_Pad1.30x1.75mm_HandSolder | 1206 5%
 |  | R3 | 10k | Device:R | Resistor_SMD:R_1206_3216Metric_Pad1.30x1.75mm_HandSolder | 1206 5%
 |  | R4 | 10k | Device:R | Resistor_SMD:R_1206_3216Metric_Pad1.30x1.75mm_HandSolder | 1206 5%
 |  | U1 | USB-C | 3dAudioSym:USB-C | 3dAudioFoot:USB-C | MO:640-USB4125-GF-A-190
 | DK ? Digikey MO ? Mouser

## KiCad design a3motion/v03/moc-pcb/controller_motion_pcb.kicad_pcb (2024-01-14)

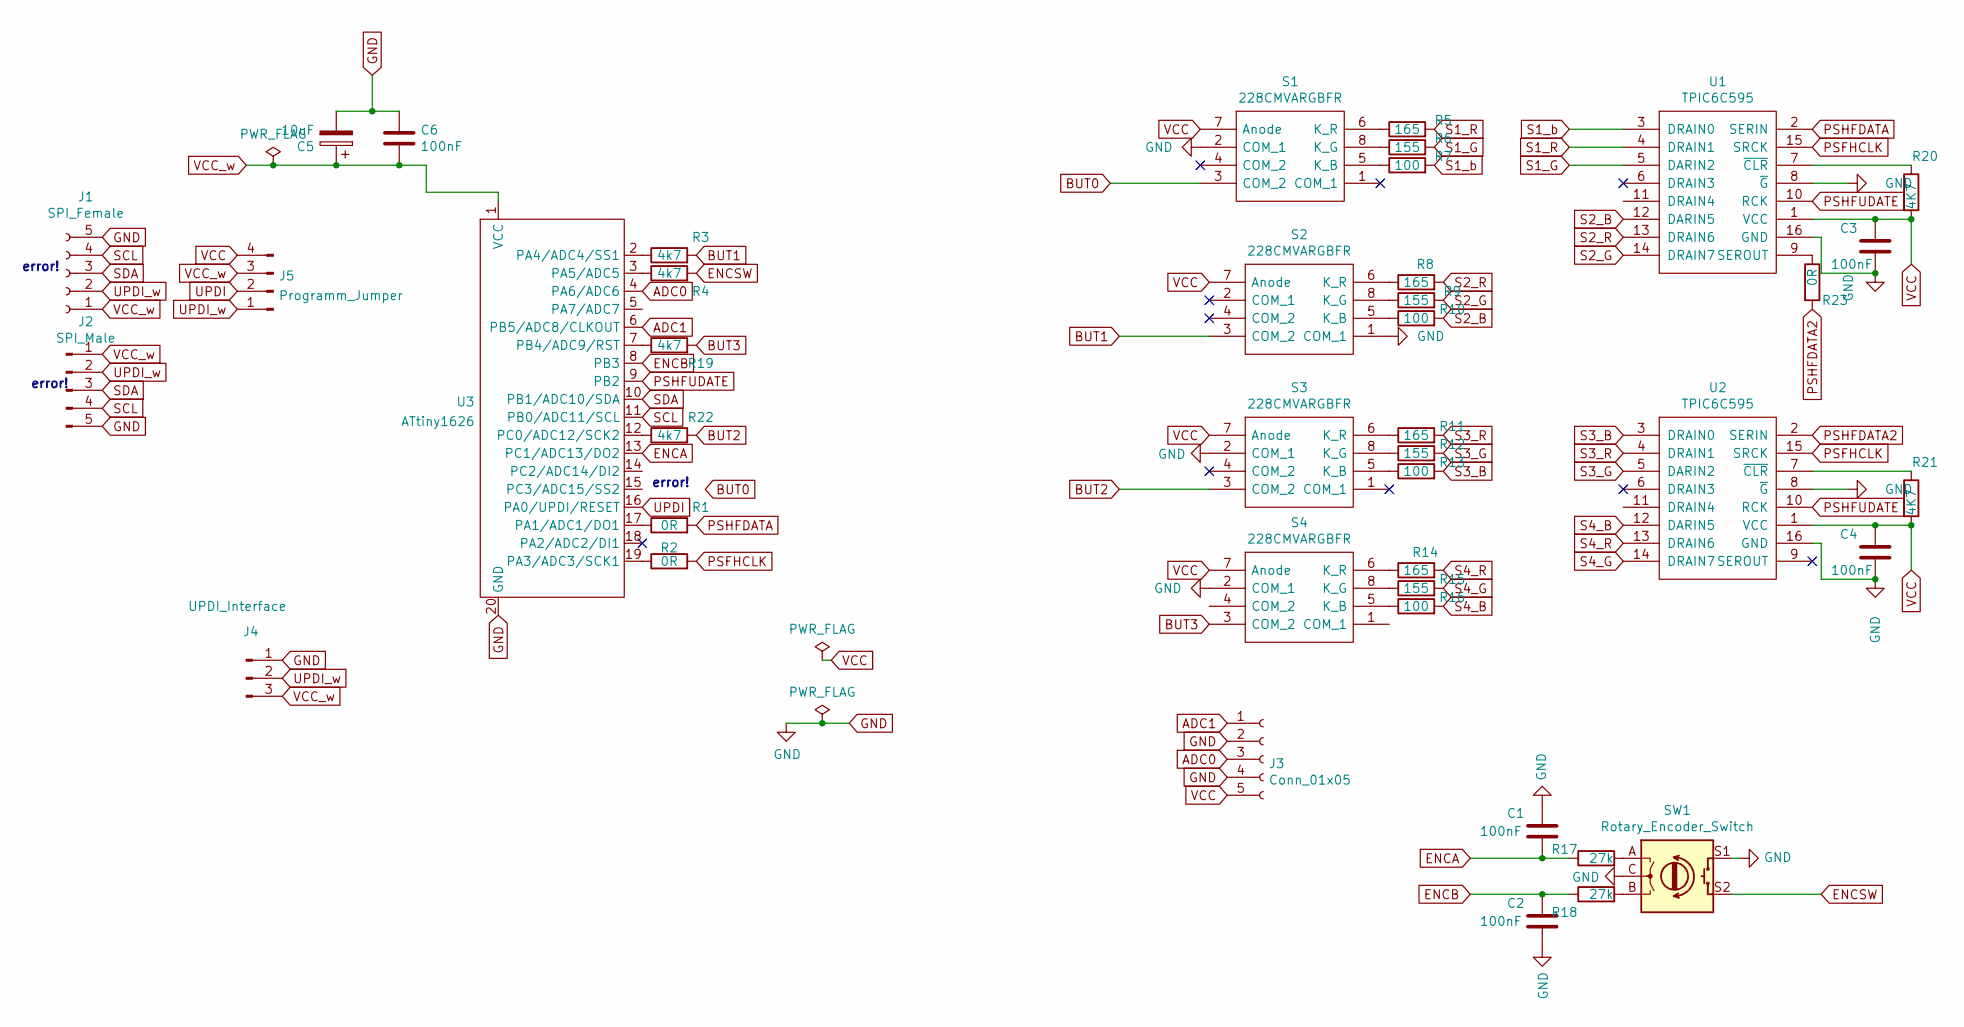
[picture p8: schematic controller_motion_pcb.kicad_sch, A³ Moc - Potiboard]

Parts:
C1, C2, C3, C4, C6: 100nF; C_1206_3216Metric_Pad1.33x1.80mm_HandSolder
C5: 10uF; CP_Radial_D4.0mm_P1.50mm
J1: SPI_Female; PinSocket_1x05_P2.54mm_Horizontal
J2: SPI_Male; PinHeader_1x05_P2.54mm_Horizontal
J3: Conn_01x05; JST_XH_B5B-XH-A_1x05_P2.50mm_Vertical
J4: UPDI_Interface; PinHeader_1x03_P2.54mm_Vertical
J5: Programm_Jumper; PinHeader_2x02_P2.54mm_Vertical
R1, R2, R23: 0R; R_1206_3216Metric_Pad1.30x1.75mm_HandSolder
R3, R4, R19, R22: 4k7; R_1206_3216Metric_Pad1.30x1.75mm_HandSolder
R5, R8, R11, R14: 165; R_1206_3216Metric_Pad1.30x1.75mm_HandSolder
R6, R9, R12, R15: 155; R_1206_3216Metric_Pad1.30x1.75mm_HandSolder
R7, R10, R13, R16: 100; R_1206_3216Metric_Pad1.30x1.75mm_HandSolder
R17, R18: 27k; R_1206_3216Metric_Pad1.30x1.75mm_HandSolder
R20, R21: 4K7; R_1206_3216Metric_Pad1.30x1.75mm_HandSolder
S1, S2, S3, S4: 228CMVARGBFR; 228CMVARGBFR_SMD; Mouser Part Number 774-228CMVARGBFR
SW1: Rotary_Encoder_Switch; PEC11R4230KS0024
U1, U2: TPIC6C595; SOIC-16_3.9x9.9mm_P1.27mm
U3: ATtiny1626; attiny1626

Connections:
ADC0: J3.3, U3.4 (PA6/ADC6)
BUT0: S1.3 (COM_2)
BUT1: R3.2, S2.3 (COM_2)
BUT2: R22.2, S3.3 (COM_2)
BUT3: R19.2, S4.3 (COM_2)
ENCA: C1.2, R17.1, U3.13 (PC1/ADC13/DO2)
ENCB: C2.1, R18.1, U3.8 (PB3)
ENCSW: R4.2, SW1.S2
GND: C1.1, C2.2, C3.2, C4.2, C5.2, C6.1, J1.5, J2.5, J3.2, J3.4, J4.1, S1.2 (COM_1), S2.1 (COM_1), S3.2 (COM_1), S4.2 (COM_1), SW1.C, SW1.S1, U1.8 (~G), U1.16 (GND), U2.8 (~G), U2.16 (GND), U3.20 (GND)
unnamed: R1.1, U3.17 (PA1/ADC1/DO1)
unnamed: R2.1, U3.19 (PA3/ADC3/SCK1)
unnamed: R3.1, U3.2 (PA4/ADC4/SS1)
unnamed: R4.1, U3.3 (PA5/ADC5)
unnamed: R5.1, S1.6 (K_R)
unnamed: R6.1, S1.8 (K_G)
unnamed: R7.1, S1.5 (K_B)
unnamed: R8.1, S2.6 (K_R)
unnamed: R9.1, S2.8 (K_G)
unnamed: R10.1, S2.5 (K_B)
unnamed: R11.1, S3.6 (K_R)
unnamed: R12.1, S3.8 (K_G)
unnamed: R13.1, S3.5 (K_B)
unnamed: R14.1, S4.6 (K_R)
unnamed: R15.1, S4.8 (K_G)
unnamed: R16.1, S4.5 (K_B)
unnamed: R17.2, SW1.A
unnamed: R18.2, SW1.B
unnamed: R19.1, U3.7 (PB4/ADC9/RST)
unnamed: R20.1, U1.7 (~CLR)
unnamed: R21.1, U2.7 (~CLR)
unnamed: R22.1, U3.12 (PC0/ADC12/SCK2)
unnamed: R23.1, U1.9 (SEROUT)
PSFHCLK: R2.2, U1.15 (SRCK), U2.15 (SRCK)
PSHFDATA: R1.2, U1.2 (SERIN)
PSHFDATA2: R23.2, U2.2 (SERIN)
PSHFUDATE: U1.10 (RCK), U2.10 (RCK), U3.9 (PB2)
S1_G: R6.2, U1.5 (DARIN2)
S1_R: R5.2, U1.4 (DRAIN1)
S1_b: R7.2, U1.3 (DRAIN0)
S2_B: R10.2, U1.12 (DARIN5)
S2_G: R9.2, U1.14 (DRAIN7)
S2_R: R8.2, U1.13 (DRAIN6)
S3_B: R13.2, U2.3 (DRAIN0)
S3_G: R12.2, U2.5 (DARIN2)
S3_R: R11.2, U2.4 (DRAIN1)
S4_B: R16.2, U2.12 (DARIN5)
S4_G: R15.2, U2.14 (DRAIN7)
S4_R: R14.2, U2.13 (DRAIN6)
SCL: J1.4, J2.4, U3.11 (PB0/ADC11/SCL)
SDA: J1.3, J2.3, U3.10 (PB1/ADC10/SDA)
UPDI: J5.2, U3.16 (PA0/UPDI/RESET)
UPDI_w: J1.2, J2.2, J4.2, J5.1
VCC_w: C5.1, C6.2, J1.1, J2.1, J4.3, J5.3, U3.1 (VCC)

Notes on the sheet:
error!

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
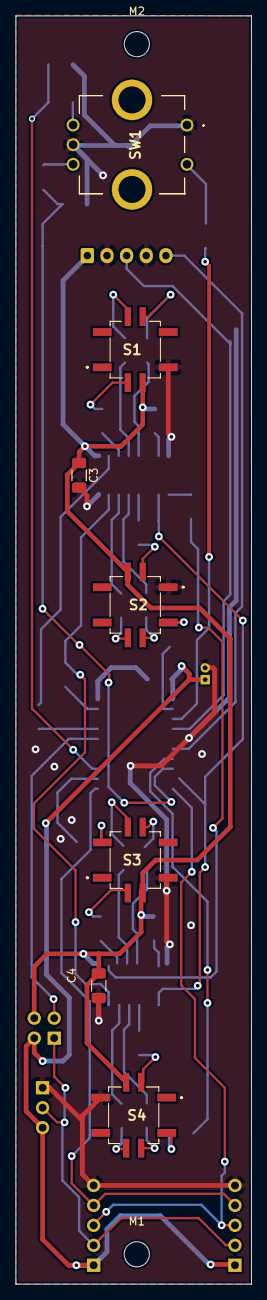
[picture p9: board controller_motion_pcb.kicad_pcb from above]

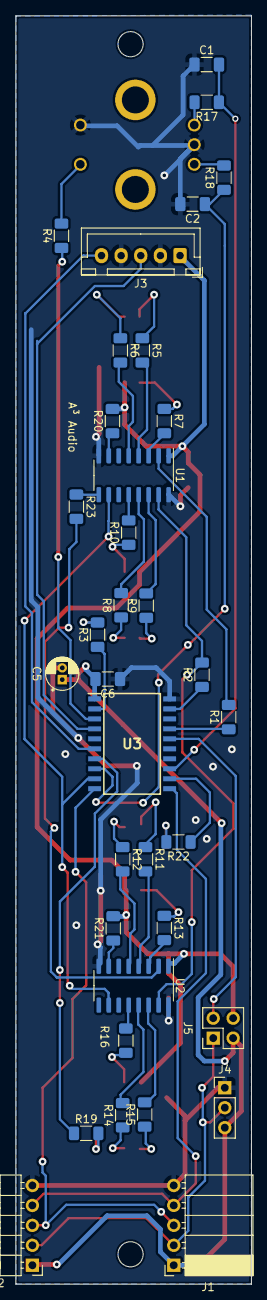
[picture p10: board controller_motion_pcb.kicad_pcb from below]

Board: 2 copper layers, 30.0 x 161.5 mm, 44 parts (35 on the bottom side), 54 nets.

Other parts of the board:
M1, M2: MountingHole_3.2mm_M3

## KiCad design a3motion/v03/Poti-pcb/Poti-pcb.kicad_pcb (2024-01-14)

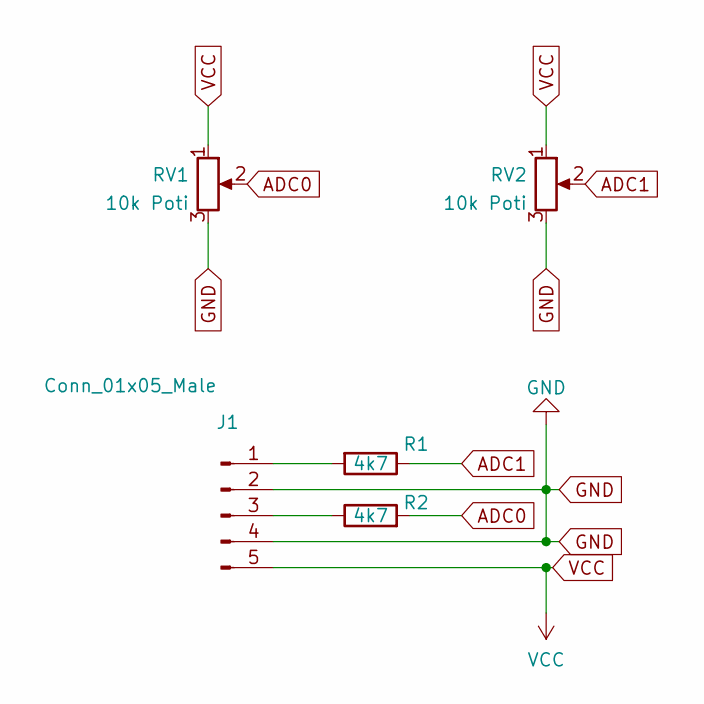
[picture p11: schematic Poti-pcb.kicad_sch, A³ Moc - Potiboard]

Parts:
J1: Conn_01x05_Male; JST_XH_B5B-XH-A_1x05_P2.50mm_Vertical
R1, R2: 4k7; R_1206_3216Metric_Pad1.30x1.75mm_HandSolder
RV1, RV2: 10k Poti; Potentiometer_Alpha_RD901F-40-00D_Single_Vertical_CircularH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

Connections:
ADC0: R2.2, RV1.2
ADC1: R1.1, RV2.2
GND: J1.2, J1.4, RV1.3, RV2.3
unnamed: J1.1, R1.2
unnamed: J1.3, R2.1
VCC: J1.5, RV1.1, RV2.1

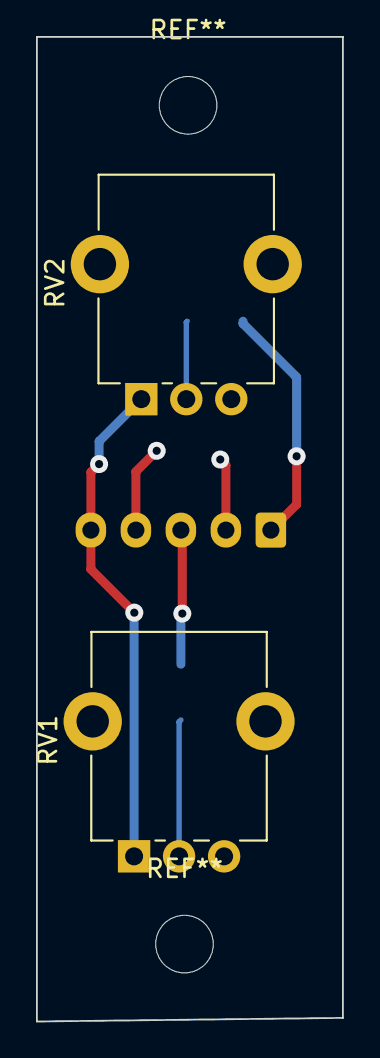
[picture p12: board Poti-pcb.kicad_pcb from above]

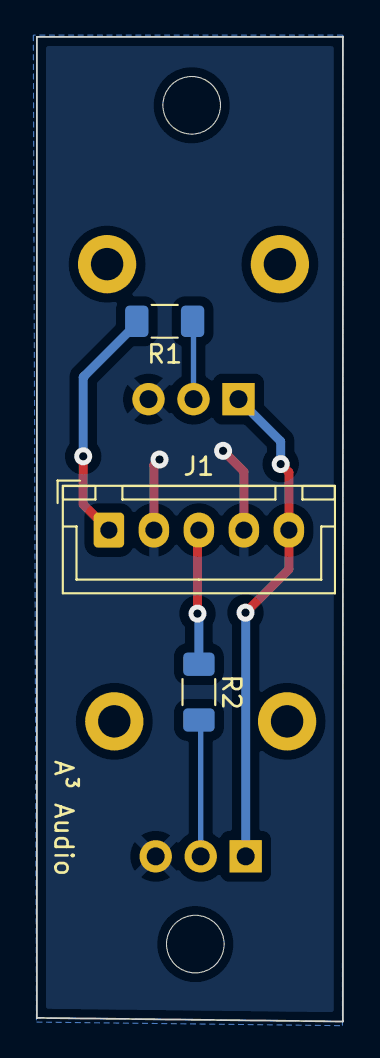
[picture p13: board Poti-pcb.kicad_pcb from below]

Board: 2 copper layers, 17.0 x 54.7 mm, 5 parts (3 on the bottom side), 6 nets.

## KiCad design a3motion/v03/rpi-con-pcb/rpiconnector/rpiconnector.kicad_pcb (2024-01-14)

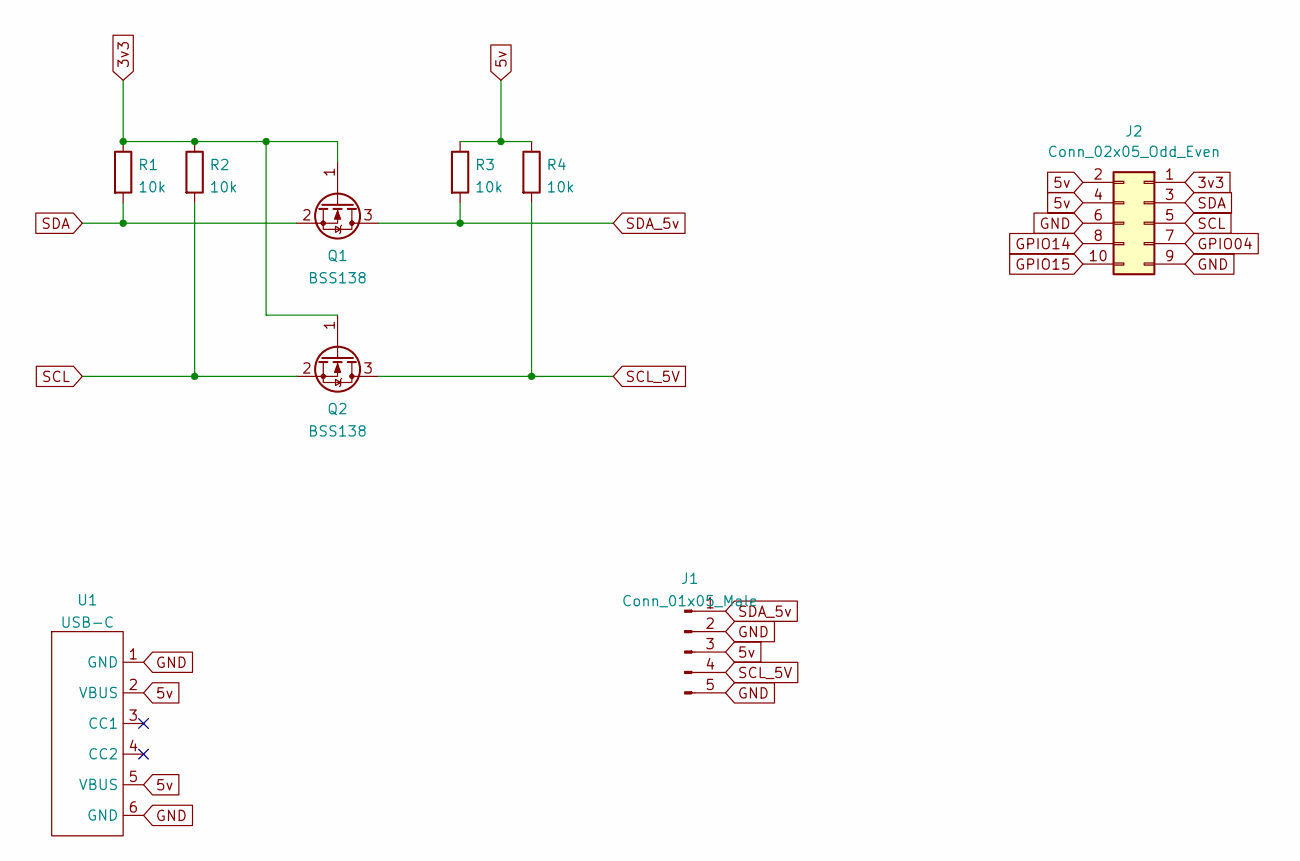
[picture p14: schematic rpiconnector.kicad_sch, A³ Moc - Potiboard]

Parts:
J1: Conn_01x05_Male; PinHeader_1x05_P2.54mm_Vertical
J2: Conn_02x05_Odd_Even; PinSocket_2x05_P2.54mm_Vertical
Q1, Q2: BSS138
R1, R2, R3, R4: 10k; R_1206_3216Metric_Pad1.30x1.75mm_HandSolder
U1: USB-C

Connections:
3v3: J2.1, Q1.1 (G), Q2.1 (G), R1.1, R2.1
5v: J1.3, J2.2, J2.4, R3.1, R4.1, U1.2 (VBUS), U1.5 (VBUS)
GND: J1.2, J1.5, J2.6, J2.9, U1.1 (GND), U1.6 (GND)
GPIO04: J2.7
GPIO14: J2.8
GPIO15: J2.10
SCL: J2.5, Q2.2 (S), R2.2
SCL_5V: J1.4, Q2.3 (D), R4.2
SDA: J2.3, Q1.2 (S), R1.2
SDA_5v: J1.1, Q1.3 (D), R3.2

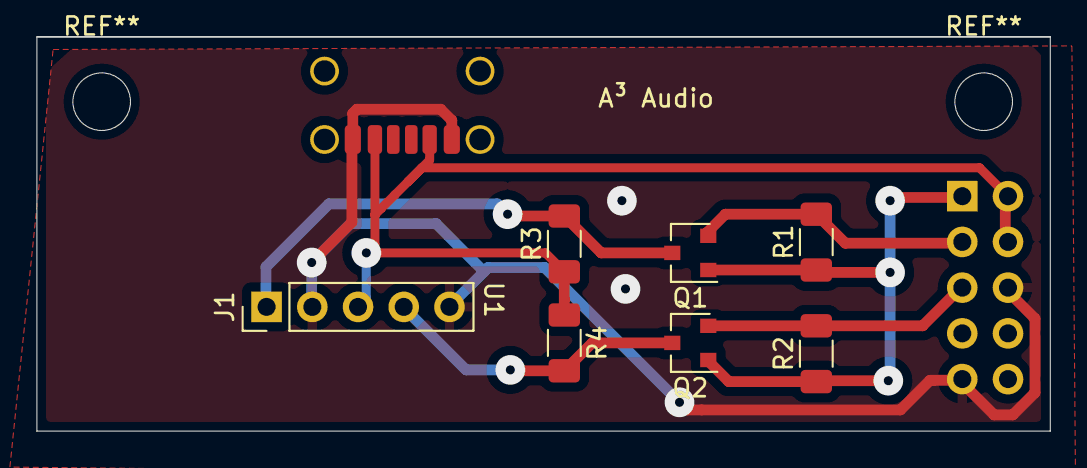
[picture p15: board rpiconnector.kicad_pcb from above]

Board: 2 copper layers, 56.3 x 21.9 mm, 9 parts (1 on the bottom side), 7 nets.

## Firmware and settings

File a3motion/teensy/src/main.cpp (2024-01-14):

// This file is a part of A³Pandemic. License is GPLv3: https://github.com/ambisonics-audio-association/Ambijockey/blob/main/COPYING
// © Copyright 2021 Jendrik Bradaczek 

/*
um es später schön zu machen:

Bounce pushbutton = Bounce(PIN_BUTTON_ENCODER, 10);
pinMode(PIN_BUTTON_ENCODER, INPUT_PULLUP);
  if (pushbutton.update())
  {
    if (pushbutton.fallingEdge())
    {
        // ...
    }
  }
*/

#include <Arduino.h>
#include <Encoder.h>
#include <Adafruit_NeoPixel.h>

// Multiplexer In/Out Pin's
#define muxInBtnMx1 20 //Butten Matrix
#define muxInBtnMx2 19 //Butten Matrix
#define muxInPot 18    //Poti in
#define muxInBtnEncoder 8 //Encoder Buttons in

// Multiplexer address Pin's (s0/s1/s2)
#define s0 23 // low-order bit
#define s1 22
#define s2 21 // high-order bit

// encoder pins
#define enc0_DT 0
#define enc0_CLK 1
#define enc1_DT 2
#define enc1_CLK 3
#define enc2_DT 4
#define enc2_CLK 5
#define enc3_DT 6
#define enc3_CLK 7

// NeoPixel
#define npxl_pin 9
#define npxl_leds 16
Adafruit_NeoPixel strip = Adafruit_NeoPixel(npxl_leds, npxl_pin, NEO_GRB + NEO_KHZ800);

// multipexer adrress Bit
bool addrBit0 = 0;
bool addrBit1 = 0;
bool addrBit2 = 0;

// btnMatrx arry
bool btnMxNew[16];
bool btnMxOld[16];

// poti arry
int potiNew[8];
int potiOld[8];

// BtnEncoder
bool btnEncoderNew[8];
bool btnEncoderOld[8];

// Encoder def
Encoder enc0(enc0_DT, enc0_CLK);
Encoder enc1(enc1_DT, enc1_CLK);
Encoder enc2(enc2_DT, enc2_CLK);
Encoder enc3(enc3_DT, enc3_CLK);

long posEnc0 = 0;
long posEnc1 = 0;
long posEnc2 = 0;
long posEnc3 = 0;

long newEnc0 = 0;
long newEnc1 = 0;
long newEnc2 = 0;
long newEnc3 = 0;

void initBtnMatrix()
{
  // btnMatrix init
  for (byte i = 0; i < 16; i++)
  {
    btnMxNew[i] = 0;
    btnMxOld[i] = 0;
  }
}

void sendBtnMx()
{
  for (byte i = 0; i < 16; i++)
  {
    if (btnMxNew[i] != btnMxOld[i])
    {
      Serial.print("B");
      Serial.print(i);
      Serial.print(":");
      Serial.println(btnMxNew[i]);
      btnMxOld[i] = btnMxNew[i];
    }
  }
}

void initPoti()
{
  pinMode(muxInBtnMx1, INPUT_PULLDOWN);
  pinMode(muxInBtnMx2, INPUT_PULLDOWN);
  for (byte i = 0; i < 8; i++)
  {
    potiNew[i] = 0;
    potiOld[i] = 0;
  }
}

void sendPoti()
{
  for (byte i = 0; i < 8; i++)
  {
    if (abs(potiNew[i] - potiOld[i]) > 3)
    {
      Serial.print("P");
      Serial.print(i);
      Serial.print(":");
      Serial.println(potiNew[i]);
      potiOld[i] = potiNew[i];
    }
  }
}

void readMux()
{
  for (byte i = 0; i < 8; i++)
  {
    addrBit0 = bitRead(i, 0);
    addrBit1 = bitRead(i, 1);
    addrBit2 = bitRead(i, 2);
    digitalWrite(s0, addrBit0);
    digitalWrite(s1, addrBit1);
    digitalWrite(s2, addrBit2);
    delayMicroseconds(10); // Damit der 4051 zeit hat die Adresse um zu schalten

    // read buttonmatrix
    btnMxNew[i] = digitalRead(muxInBtnMx1);
    btnMxNew[i + 8] = digitalRead(muxInBtnMx2);

    // read encoder buttons
    btnEncoderNew[i] = digitalRead(muxInBtnEncoder);

    // read potentiometer
    potiNew[i] = analogRead(muxInPot);
  }
}

void initBtnEncoder()
{
  for (byte i = 0; i < 4; i++)
  {
    btnEncoderNew[i] = 0;
    btnEncoderOld[i] = 0;
  }
}

void initLEDs()
{
    strip.clear();
    strip.show();
}

void sendBtnEncoder()
{
  for (byte i = 0; i < 4; i++)
  {
    if (btnEncoderNew[i] != btnEncoderOld[i])
    {
      Serial.print("EB");
      Serial.print(i);
      Serial.print(":");
      Serial.println(btnEncoderNew[i]);
      btnEncoderOld[i] = btnEncoderNew[i];
    }
  }
}

void readEncoder()
{
  newEnc0 = enc0.read();
  newEnc1 = enc1.read();
  newEnc2 = enc2.read();
  newEnc3 = enc3.read();
}

void sendEncoder()
{
  if (newEnc0 != posEnc0)
  {
    Serial.print("Enc0:");
    Serial.println(newEnc0);
    posEnc0 = newEnc0;
  }

  if (newEnc1 != posEnc1)
  {
    Serial.print("Enc1:");
    Serial.println(newEnc1);
    posEnc1 = newEnc1;
  }

  if (newEnc2 != posEnc2)
  {
    Serial.print("Enc2:");
    Serial.println(newEnc2);
    posEnc2 = newEnc2;
  }

  if (newEnc3 != posEnc3)
  {
    Serial.print("Enc3:");
    Serial.println(newEnc3);
    posEnc3 = newEnc3;
  }
}

void receivePixels(){
  if (Serial.available()) {
    String command = Serial.readStringUntil(',');
    if(command.startsWith("L")) {
      int pixNum  = Serial.readStringUntil(',').toInt();
      int red = Serial.readStringUntil(',').toInt();
      int green = Serial.readStringUntil(',').toInt();
      int blue  = Serial.readStringUntil('\n').toInt();

      strip.setPixelColor(pixNum, strip.Color(green, red, blue));
      strip.show(); // This sends the updated pixel color to the hardware.
    }
  }
}

void setup()
{
  Serial.begin(115200);
  Serial.setTimeout(10);
  while (!Serial)
  {
    ; // wait for serial conaction
  }
  Serial.println("#######################################");
  Serial.println("          controller connected");
  Serial.println("#######################################");

  initBtnMatrix();
  initBtnEncoder();
  initPoti();
  initLEDs();

  strip.begin();

}

void loop()
{
  readMux();
  readEncoder();

  sendBtnMx();
  sendBtnEncoder();
  sendEncoder();
  sendPoti();

  receivePixels();
}

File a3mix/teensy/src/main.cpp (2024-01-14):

// This file is a part of A³Mix.
// License is GPLv3: https://github.com/ambisonics-audio-association/Ambijockey/blob/main/COPYING
// © Copyright 2021-2022 Raphael Eismann, Patric Schmitz

// Made for A³Mix PCB v0.2

#include <array>

#include <Arduino.h>
#include <Adafruit_NeoPixel.h>
#include <LedControl.h>

#include <Bounce.h>

const int debounce_ms = 10;
const uint8_t pin_states[2] = { HIGH, LOW };

//////////// PIN ASSIGNMENTS //////////////

const int PINS_LED_PER_CHANNEL [] = {26, 38, 39, 40};
const int PINS_BUTTON_0_PER_CHANNEL [] = {33, 34, 35, 36};
Bounce button_0_per_channel [] = {
    Bounce(PINS_BUTTON_0_PER_CHANNEL[0], debounce_ms),
    Bounce(PINS_BUTTON_0_PER_CHANNEL[1], debounce_ms),
    Bounce(PINS_BUTTON_0_PER_CHANNEL[2], debounce_ms),
    Bounce(PINS_BUTTON_0_PER_CHANNEL[3], debounce_ms)
};

const int multiplexer[6] = {5, 6, 7, 8, 9}; // Channel pots [0-3],
                                            // Master pots [4]
const int multiplexer_enc = 12; // Encoderswitches (digital)
const int selectPins[3] = {30, 31, 32}; // Multiplexer abc

// track the bounce state for 8 buttons on the multiplexer, which are
// all connected to the same teensy pin.
const int PIN_BUTTONS_1_2_MULTIPLEX_PER_CHANNEL = 27;
Bounce buttons_1_2_multiplex_per_channel [] = {
    Bounce(PIN_BUTTONS_1_2_MULTIPLEX_PER_CHANNEL, debounce_ms),
    Bounce(PIN_BUTTONS_1_2_MULTIPLEX_PER_CHANNEL, debounce_ms),
    Bounce(PIN_BUTTONS_1_2_MULTIPLEX_PER_CHANNEL, debounce_ms),
    Bounce(PIN_BUTTONS_1_2_MULTIPLEX_PER_CHANNEL, debounce_ms),
    Bounce(PIN_BUTTONS_1_2_MULTIPLEX_PER_CHANNEL, debounce_ms),
    Bounce(PIN_BUTTONS_1_2_MULTIPLEX_PER_CHANNEL, debounce_ms),
    Bounce(PIN_BUTTONS_1_2_MULTIPLEX_PER_CHANNEL, debounce_ms),
    Bounce(PIN_BUTTONS_1_2_MULTIPLEX_PER_CHANNEL, debounce_ms),
};

const int num_fx_buttons = 2;
const int PINS_BUTTON_FX [] = {28, 29};
Bounce buttons_fx [] = {
    Bounce(PINS_BUTTON_FX[0], debounce_ms),
    Bounce(PINS_BUTTON_FX[1], debounce_ms),
};

const int display_sda1 = 17;
const int display_scl1 = 16;
const int display_sda2 = 25;
const int display_scl2 = 24;

// last sent states (potis)
const int num_channels = 4;
const int num_tracks = 6; // including master and fx sections
const int num_pots = 8;
int pots_sent[num_tracks][num_pots];

const std::array<std::string, 6> track_names = {
    "0",
    "1",
    "2",
    "3",
    "master",
    "fx",
};

// vu-meter neopixel
const int npxl_pin = 13; // pcb pin
const int npxl_leds = 32;// striplength
Adafruit_NeoPixel pixels = Adafruit_NeoPixel(npxl_leds, npxl_pin, NEO_GRB + NEO_KHZ800);

int vupxlstrips[4][8] = {
    {7,6,5,4,3,2,1,0},
    {15,14,13,12,11,10,9,8},
    {23,22,21,20,19,18,17,16},
    {31,30,29,28,27,26,25,24}
};

// LED matrix
LedControl lc = LedControl(18,14,15,4); // led-matrix pins
int modePxl[4][3] = {
    {0,1,2},
    {12,13,14},
    {24,25,26},
    {36,37,38}
};

// Rotary Encoder pin mapping
// const int rEnc0_DT = 0;
// const int rEnc0_clk = 1;
// const int rEnc1_DT = 2;
// const int rEnc1_clk = 3;
// const int rEnc2_DT = 4;
// const int rEnc2_clk = 5;
// const int rEnc3_DT = 6;
// const int rEnc3_clk = 7;
// const int rEnc4_DT = 8;
// const int rEnc4_clk = 9;
// const int rEnc5_DT = 10;
// const int rEnc5_clk = 11;

// const int spare_1 = 28;
// const int spare_2 = 29;

void setup()
{

    // initialize sent values to 0
    for(int track = 0 ; track < num_tracks ; ++track) {
        for(int pot = 0 ; pot < num_pots ; ++pot) {
            pots_sent[track][pot] = 0;
        }
    }

    Serial.begin(115200);       // starting Serial
    pixels.begin(); 		// INITIALIZE NeoPixel
    pixels.clear();
    pixels.setBrightness(2);

    // Configure per-channel digital pins
    for(int channel = 0 ; channel < num_channels ; ++channel) {
        pinMode(PINS_BUTTON_0_PER_CHANNEL[channel], INPUT);
        pinMode(PINS_LED_PER_CHANNEL[channel], OUTPUT);
    }

    for(int button = 0 ; button < num_fx_buttons ; ++button) {
        pinMode(PINS_BUTTON_FX[button], INPUT);
    }

    lc.shutdown(0,false);
    lc.shutdown(1,false);
    lc.shutdown(2,false);
    lc.shutdown(3,false);

    // Set brightness
    lc.setIntensity(0,1);
    lc.setIntensity(1,1);
    lc.setIntensity(2,1);
    lc.setIntensity(3,1);
}

void loop()
{
    // first read per-track button 0 directly (no mux)
    for(int channel = 0 ; channel < num_channels ; ++channel) {
        if(button_0_per_channel[channel].update()) {
            Serial.print("T");
            Serial.print(":");
            Serial.print(channel);
            Serial.print(":");
            Serial.print("B");
            Serial.print(":0:");
            Serial.println(button_0_per_channel[channel].risingEdge() ? "1" : "0");
        }
    }

    // read pots and fx/3d buttons via hc4051 multiplexer
    for (byte pin=0 ; pin < 8 ; ++pin)
    {
        // hc4051 pinselector abc (binary)
        for (int i=0; i<3; i++) {
            digitalWrite(selectPins[i], pin & (1 << i) ? HIGH : LOW); // select hc4051
        }
        delayMicroseconds(10);

        // the four tracks [0-3] and the master track [4] are read
        // as fully analog inputs.
        for (int track=0 ; track < 5; ++track) {
            int analog = analogRead(multiplexer[track]);
            int difference = pots_sent[track][pin] - analog;

            // filter analog inputs
            // send osc when difference larger than noise on
            // last bits
            // @TODO this needs to be solved in hardware!
            if(abs(difference) > 8) {
                pots_sent[track][pin] = analog;
                float sendValue = float(analog) / 1023.f;
                Serial.print("T");
                Serial.print(":");
                Serial.print(track_names[track].c_str());
                Serial.print(":");
                Serial.print("P");
                Serial.print(":");
                Serial.print(pin);
                Serial.print(":");
                Serial.println(sendValue, 6);
            }
        }

        // read buttons 1, 2 per channel
        if(buttons_1_2_multiplex_per_channel[pin].update()) {
            Serial.print("T:");
            Serial.print(pin%4);
            Serial.print(":B:");
            Serial.print(1 + pin/4);
            Serial.print(":");
            Serial.println(buttons_1_2_multiplex_per_channel[pin].risingEdge() ? "1" : "0");
        }
    }

    // read buttons separately for FX track [5]
    for(int button = 0 ; button < num_fx_buttons ; ++button) {
        if(buttons_fx[button].update()) {
            Serial.print("T:");
            Serial.print(track_names[5].c_str());
            Serial.print(":B:");
            Serial.print(button);
            Serial.print(":");
            Serial.println(buttons_fx[button].risingEdge() ? "1" : "0");
        }
    }

    delayMicroseconds(10);

    if (Serial.available()) {
        String command = Serial.readStringUntil(':');
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

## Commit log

2020-10-17 edit und noch mal... XO
2020-10-22 1st Controller_Mixer pcb (kicad-Pproject
    [controller_mixer_pcb.kicad_pcb, controller_mixer_pcb.sch]
2020-10-22 1st Controller_Mixer pcb fertig
    [controller_mixer_pcb.kicad_pcb, controller_mixer_pcb.sch]
2020-10-22 bunt bunt und in farbe
2020-10-24 buck fix
2020-10-29 daily edits
    [controller_mixer_pcb.kicad_pcb, controller_mixer_pcb.sch]
2020-11-02 noch mal sauber die gerber fils erzeugen
    [controller_motion_pcb-B_Cu.gbr, controller_motion_pcb-B_Mask.gbr, controller_motion_pcb-B_Paste.gbr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]
2020-11-03 short buck fix
2020-12-21 mic aufgeräumt und richtig
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2020-12-26 mic.py läuft, osc-messages vom mic sind jetzt lesbar und via serial statt eth
2020-12-27 auf raeumen
    [Buttonmatrix_pcb.kicad_pcb, Buttonmatrix_pcb.sch]
2020-12-27 add ch-selektion over endoder button
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2020-12-28 clean up
    [tecRider.ods]
2020-12-28 businessplan init
    [tecRider.ods]
2020-12-28 Struckturieren und zusamen tragen
    [matterialKalkulation.ods]
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2021-01-09 controller_mixer_pcb_v0.2 - Irgendwo ist angeblich ein Kurzschluss sagt der Debugger aber ich find ihn nicht...
    [controller_mixer_pcb-B_Cu.gbr, controller_mixer_pcb-B_Mask.gbr, controller_mixer_pcb-B_Paste.gbr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]
2021-01-09 controller_mixer_pcb_v0.2 - edits
    [mixer.pcb.sch]
2021-01-09 add LED Matrix vu
    [mixer.pcb.sch]
2021-01-10 fix versuch
    [mixer.pcb.sch]
2021-01-10 corrections mixer_pcb
    [mixer.pcb.sch]
2021-01-17 add initial version of moc python UI
    using fixed size layout for now
    [moc.py]
2021-01-19 mixer pcb v0.2 ready?
    [mixer.pcb.kicad_pcb, mixer.pcb.sch]
2021-01-25 neu kalkulation
    [Kalkulation.ods]
2021-01-28 InputAdapterOSC.py serial to ui aber wie?
    [config.txt]
2021-01-29 first working serial line handler with proper inter-thread calling
2021-01-29 correct slot signature for encoder_pressed/released
2021-01-30 use signals properly to call slots from different thread
2021-01-31 add .xinitrc to repos
    [config.txt]
2021-01-31 clamp sides to 9db
2021-02-07 switch layer for mixer_pcb
    [mixer.pcb.kicad_pcb]
2021-02-07 move to own RP
    [Kalkulation.ods, tecRider.ods]
2021-02-08 mixer pcb
    [mixer.pcb.kicad_pcb, mixer.pcb.sch]
2021-02-08 corrections mixer-pcb
    [mixer.pcb.kicad_pcb]
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2021-02-16 mixer-pcb edits
    [mixer.pcb.kicad_pcb, mixer.pcb.sch]
2021-03-04 mixer-pcb ready
    [mixer.pcb-B_CrtYd.gbr, mixer.pcb-B_Cu.gbr, mixer.pcb-B_Fab.gbr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]
2021-03-04 gerber ready
    [mixer.pcb-B_Adhes.gbr, mixer.pcb-B_CrtYd.gbr, mixer.pcb-B_Cu.gbr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]
2021-03-20 pcb v0.2 - this went to jlcpcb and hopefully it works this time.
    [mixer.pcb-B_Adhes.gbr, mixer.pcb-B_CrtYd.gbr, mixer.pcb-B_Cu.gbr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]
2021-04-03 mixer-pcb v0.2 is running - wohoo
2021-04-05 add main.cpp vu-meter draft for aaa-mix teensy
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2021-04-09 How to get my code threading?
2021-04-11 fix led update loop for vus
    [main.cpp]
2021-04-11 avoid taking log(0) to avoid numerical error
    [mic.py]
2021-04-11 don't clear led's per loop but write all leds per message
2021-04-11 invert y indexing inside module
    [main.cpp]
2021-04-11 fix loop index and remove leftover line
    [main.cpp]
2021-04-12 mic.py switch of: print to console
2021-04-12 aaa-connections.jmess update because led vu-matrix is horizontally mirrored
2021-04-12 mic.py send mode-buttons to server.py
2021-04-12 mic.py to teensy mode-sends
2021-05-18 cleanup and describe
    [config.txt, pyvenv.cfg]
2021-05-18 edits on landing README.md
2021-05-31 add btn-matrix_pcb
    [btn-matrix-B_Cu.gbl, btn-matrix-B_Mask.gbs, btn-matrix-B_Paste.gbp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]
2021-06-02 modeLED exklusivity not working (teensy code)
    [main.cpp]
2021-06-04 blind attempt at fixing mode led code
    [main.cpp]
2021-08-04 CC BY-NC-SA 4.0 license for hardware ready
    [ButtenMatrix.stl, Button.stl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]
2021-08-19 setup raspberry 4 (still works for raspi 3)
2021-08-26 add buttonmatrix parts
    [btn-matrix-B_Cu.gbl, btn-matrix-B_Mask.gbs, btn-matrix-B_Paste.gbp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]
2021-09-23 doc and cleanup
    [btn-matrix-B_Cu.gbl, btn-matrix-B_Mask.gbs, btn-matrix-B_Paste.gbp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]
2021-09-28 A³ Assembly documentation and pics
    [mixer.pcb-B_Adhes.gbr, mixer.pcb-B_CrtYd.gbr, mixer.pcb-B_Cu.gbr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]
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2021-10-01 add cc-license to schematics jpgs
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2021-10-09 add MOC Housing
    [ButtenMatrix.stl, Button.stl]
2021-10-12 add STL
    [moc_housing_bottom.stl]
2021-10-18 Correction housing
    [moc_housing_bottom.obj, moc_housing_top.obj, moc_housing_top.stl]
2021-10-28 fix LED channel order and a little bit of cleanup
    [main.cpp]
2021-10-28 fix previously renamed identifier
    [main.cpp]
2021-10-30 bump mocui submodule, remove faulty gitmodules entry, track main
2021-11-18 clear button LED strip only once on init
2021-11-18 Clean the Sub
    [btn-matrix-B_Cu.gbl, btn-matrix-B_Mask.gbs, btn-matrix-B_Paste.gbp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]
2021-12-18 server.py complete refactoring. vu and encoder dispatching pending.
2021-12-18 reordering of button conditionals
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2022-02-20 edit teensy for pfl leds
2022-02-26 fix PFL track parsing, button pin mode, remove dead code, formatting
    [main.cpp]
2022-02-26 debounce pfl buttons with teensy Bounce library
2022-02-26 mic: fix serial pfl sending
    [mic.py]
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2022-02-26 debounce all buttons and put fx mode switch on spare pins
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2022-03-08 mic.py: de-duplicate per channel poti handling, remap fxfreq/fxres to master
2022-03-09 de-duplicate master section pots handling with message dictionary
2022-03-09 fx and 3d buttons condensed
2022-03-10 refactor mic - not working yet
    [mic.py]
2022-03-10 mic refactoring and redesign of serial message vocabulary
    Channel buttons and pots on the teensy side and in serial messages are
    numbered according to mixer front panel layout. All interpretation /
    mapping to specific functions happens on the python side.
    [main.cpp, mic.py]
2022-03-10 more 0-indexing fixes and changed vocabulary
    [main.cpp, mic.py]
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2022-03-10 finish mic refactoring and osc/serial vocab redesign
    [main.cpp, mic.py]
2022-03-30 a little cleanup, commenting, renaming in teensy code
2022-03-30 fix dB computation in mic.py to use base 10
    [mic.py]
2022-05-14 ready to publish
    [config.txt, pyvenv.cfg]
2022-05-23 gpl3 and reuse ready
    [config.txt, pyvenv.cfg]
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2022-09-20 finished MOC main console
    somehow the a3Hardware folder doesn't show changes in Git so i moved it temporarly to a3motion
    [controller_motion_pcb-B_Cu.gbr, controller_motion_pcb-B_Mask.gbr, controller_motion_pcb-B_Paste.gbr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]
2022-09-21 cleaned libs and finished main und rpi pcb
    [controller_motion_pcb.kicad_pcb, controller_motion_pcb.kicad_sch, rpiconnector.kicad_pcb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]
2023-03-30 created rpi test programm
    [Config_1.txt, Config_2.txt]
2023-04-21 clean up
    added eeprom functionality
    optimzed code
    led dimming works
    not tested i2c
    [Config_1.txt, Config_2.txt]
2023-07-26 github clean up
    [controller_motion_pcb-B_Cu.gbr, controller_motion_pcb-B_Mask.gbr, controller_motion_pcb-B_Paste.gbr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]
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2024-01-14 add channelmap and patchbay
    [channelmap.ods]
2024-01-14 a3mixV02 memory issue fix
    [main.cpp, mic.py]
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2024-01-14 cleanup gitmodules, use relative urls, track main branches
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2024-01-14 try to receive clock data but crashes on same port as vu
    [mic.py]
2024-01-14 rework buttons
2024-01-14 created v31
    [button_arr.kicad_sch, enc_arr.kicad_sch, led_arr.kicad_sch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]
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

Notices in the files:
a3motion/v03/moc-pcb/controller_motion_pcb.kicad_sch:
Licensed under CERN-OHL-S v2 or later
